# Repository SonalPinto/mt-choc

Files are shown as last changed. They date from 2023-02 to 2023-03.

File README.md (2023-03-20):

# Mt. Choc
<p align="center" width="100%">
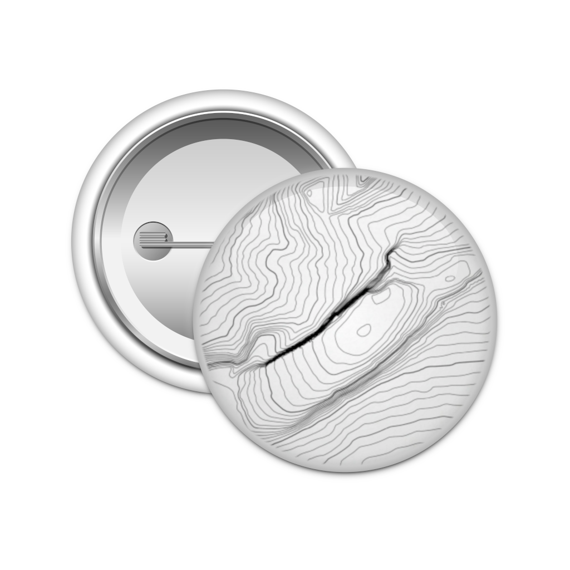
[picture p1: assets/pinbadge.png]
    
</p>

Mt. Choc is a low-profile 65% ~dark chocolate~ keyboard with a digital pin badge.







## News
- [Mt. Choc on KBD.news](https://kbd.news/Mt.-Choc-1938.html) 🎉

<p align="center" width="100%">
    <a href="http://www.youtube.com/watch?feature=player_embedded&v=3p3KzxKYGxo" target="_blank">
     Mt. Choc Glitch Effect
    </a>
</p>

## Gallery
<p align="center" width="100%">
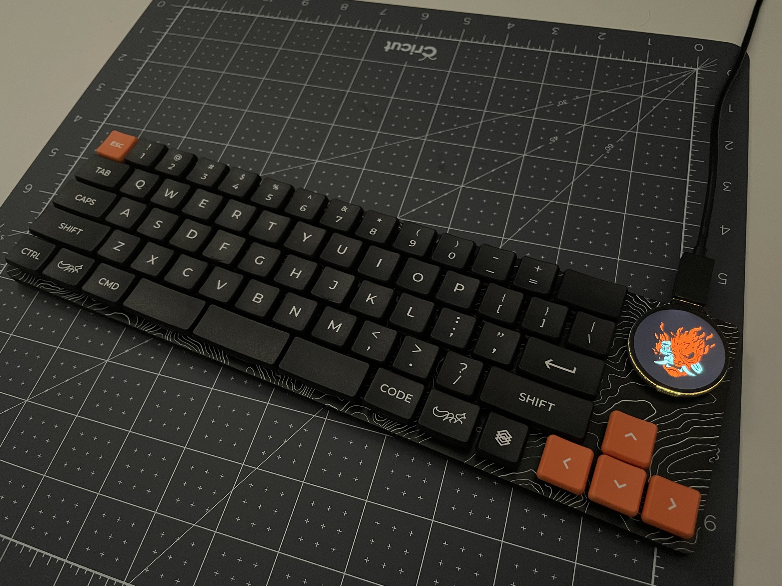
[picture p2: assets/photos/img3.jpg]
    
</p>
<p align="center" width="100%">
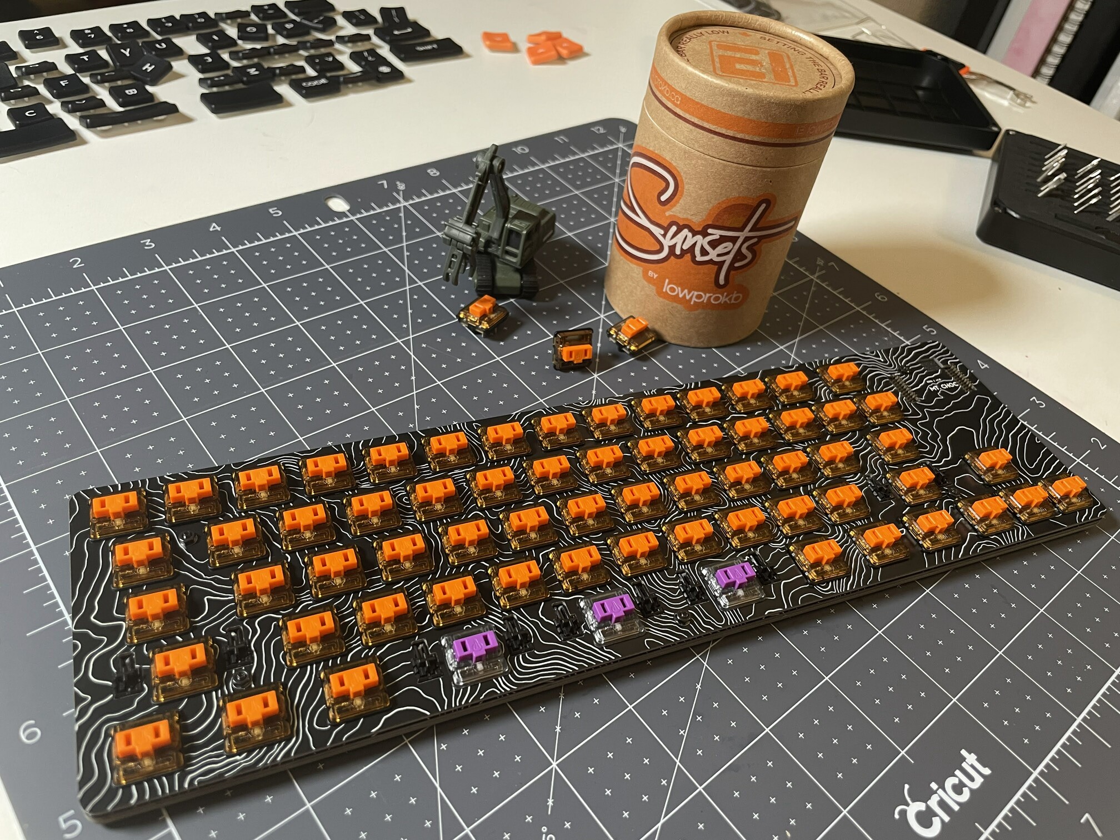
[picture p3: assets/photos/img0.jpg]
    
</p>
<p align="center" width="100%">
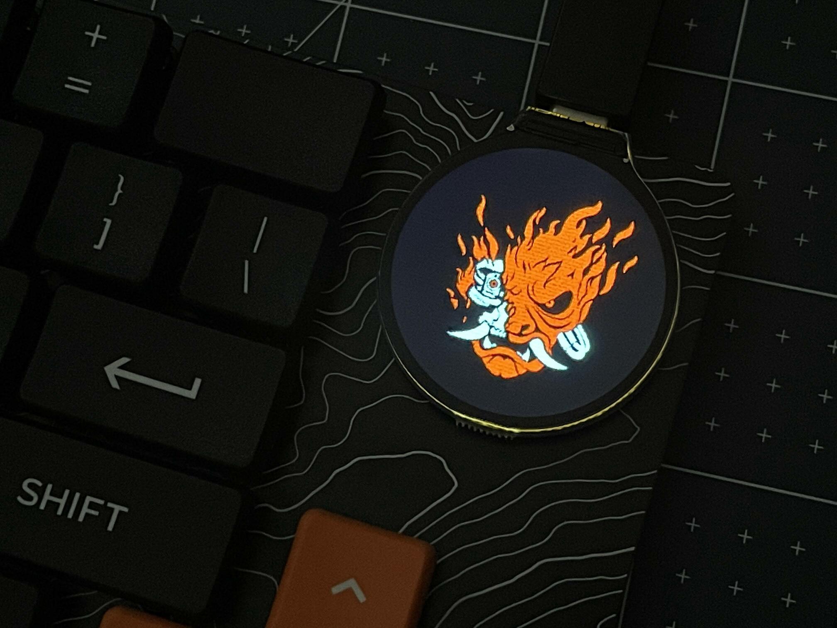
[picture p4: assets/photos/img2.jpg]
    
</p>
<p align="center" width="100%">
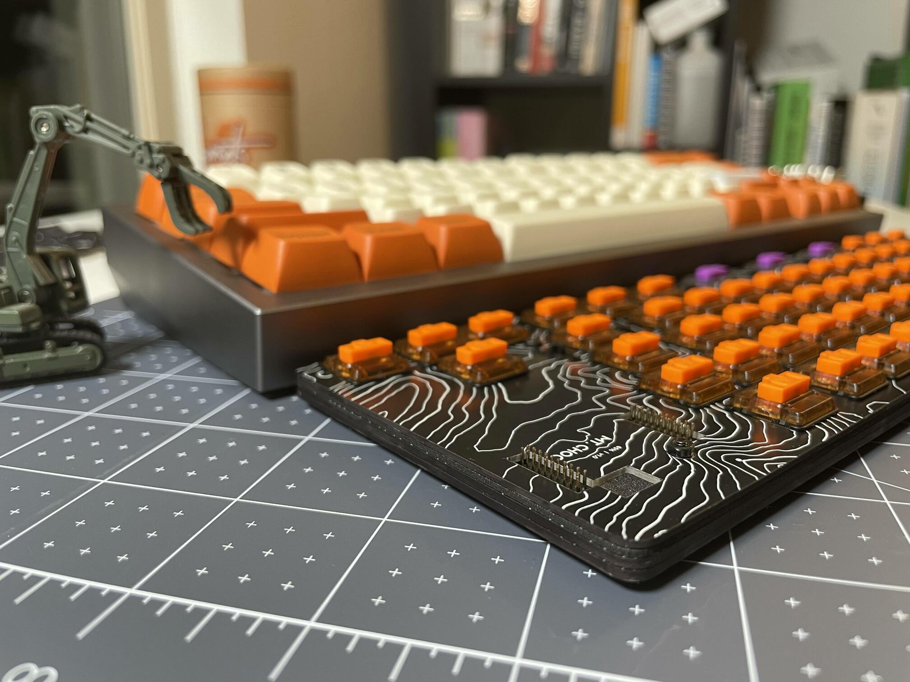
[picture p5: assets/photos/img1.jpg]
    
</p>

## Layout
A while back I had bought a box of [Sunset tactiles](https://lowprokb.ca/collections/keyboards/products/sunset-tactile-choc-switches) on a whim. I didn't really have a board in mind back then, but I knew I wanted to design a low profile board and have some kinda display on it. I had some idea brewing around since reading this ["Cyberpunk OLED glitch"](https://kbd.news/Cyberpunk-OLED-glitch-1098.html) article on KBD.news. A few weeks later, I stumbled upon [Simon's interview](https://kbd.news/Keycaps-design-and-free-kittens-1801.html) on KBD.news and saw the interest check for [MBK Legend‡ Extended](https://fkcaps.com/keycaps/mbk/legend-extended)). Everything just clicked together, and I started drafting a board.

Mt. Choc's 65% layout is designed around Kailh Choc V1 (PG1350) switches and choc-spaced keycaps (18mm wide x 17mm tall, like MBK Legend‡ Extended). The rows have the standard stagger and 6.25U spacebar. The right column is a tad narrower than usual with the intention of reducing the number of stabilizers needed. Hence, the backspace is 1.5U, the forward slash is 1U, enter is 1.75U and the right shift is 2.25U (symmetric with the left shift). The arrow cluster is offset 0.25U to right-align with the microcontroller and display. The layout does look simillar to 68-key boards like  the [Ikki68 Aurora](https://shop.wuquestudio.com/pages/ikki68-aurora) or [Varmillo Miya or VA68](https://en.varmilo.com/keyboardproscenium/product_indexsubject?layout=65&model=Theme%20keyboard), with the 2x2 keys in the top-right swapped for the display. The design is very human.

<p align="center" width="100%">
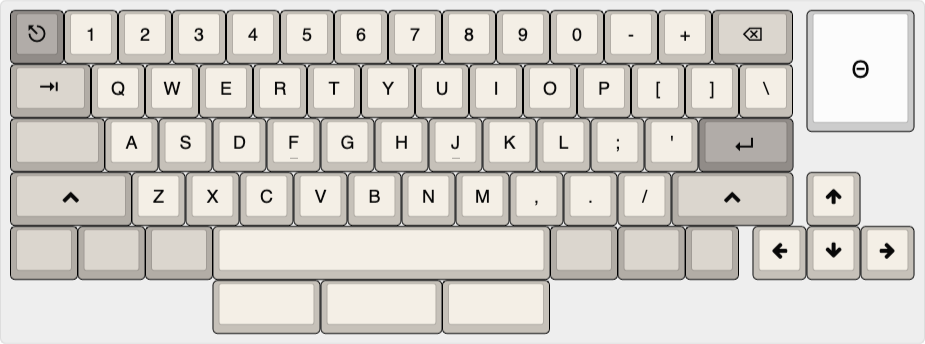
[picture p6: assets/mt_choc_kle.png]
    
</p>

The 2.25U shift on the left and right will need choc 2U stabilizers (standard 24mm wire). The 6.25U MBK spacebar uses a stabilizer that is 100mm apart (MBK spec). Opportunistically, the layout also offers an alternate spacebar layout with a split (2U-2.25U-2U) that reuses the stabilizer footprint cutouts of the 6.25U (read more in the [hardware doc](docs/hardware.md)).

With the split spacebar layout, you are left with 2U and 2.25U that use stabilizers. You could brave a build without stabilizers for these, and see where that takes you. The MX-spaced [wrk keycaps](https://worklouder.cc/keycaps/) do not appear to be using stabilizers for their 2U. I've tried this, and I wasn't a fan. So, I recommend using stabilizers for anything over 2U.

Lastly, the [round display](https://www.waveshare.com/wiki/RP2040-LCD-1.28) is like a digital pin badge for your keyboard. Give it a personal flair!

<p align="center" width="100%">
    
</p>

## Hardware
[⌨️ DOC ⌨️](docs/hardware.md)

## Build
[⌨️ DOC ⌨️](docs/build.md)

## Firmware
[⌨️ DOC ⌨️](docs/firmware.md)

## Misc
- Keyboard Layout Editor - [link](http://www.keyboard-layout-editor.com/#/gists/bee63da1aabd22d248c2b8acba987245)
- KLE raw txt - [link](docs/mt-choc-kle.txt)
- Kailh choc stabilizer spec - [link1](https://github.com/keebio/keebio-references/tree/master/Kailh%20Choc%20Stabs), [link2](assets/choc-stab-spec.jpg), [3D model](https://grabcad.com/library/kailh-choc-v1-pg1350-stabilizer-1)
- Kailh choc PG1350 spec - [link](https://cdn-shop.adafruit.com/product-files/5113/CHOC+keyswitch_Kailh-CPG135001D01_C400229.pdf)
- Kailh choc hotswap socket - [link](https://cdn-shop.adafruit.com/product-files/5118/5118-Choc-Socket.pdf)

### Compatible Keycaps
Keycaps designed for 18mm wide 1U. This is not an exhaustive list.
- [MBK Legend‡ Extended](https://fkcaps.com/keycaps/mbk/legend-extended)
- [MBK Convex POM](https://www.moergo.com/collections/mbk-convex-keycaps/products/mbk-pom-pk2?variant=44253211722001). The 2U and 2.25U would be well suited for the split spacebar. Note, this is not the same as FK Caps MBK.
- [MCC keycaps](https://splitkb.com/products/moergo-mcc-profile-1u-keycap)
- [ChosFox CFX](https://chosfox.com/products/chocfox-legends-keycap-set?variant=42753190461634). Ok, technically, I am not sure if CFX was designed for 18mm wide spacing. My measurements say that they may have been designed for 19mm (or 19.05mm) spacing. However, when placed on the 18mm wide spaced board, I couldn't tell if anything was off (at least the left/right mod columns appear ok~ish).

## Credits
- Simon ([FK Caps](https://fkcaps.com/)) and folks on FK Caps [Discord](https://discord.gg/b5C9H99RYZ)
- skarrman's [Horizon keyboard](https://github.com/skarrmann/horizon/)
- FK Caps [mbk-footprints](https://github.com/FKcaps/mbk-footprints)
  - Based off of nicoles' [mbk-footprints](https://github.com/nicoles/mbk_footprints)
- Wife for photography and coming up with the name

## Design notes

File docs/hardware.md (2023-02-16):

# Hardware

The **minimalist** build for Mt. Choc is inspired by the "PCB-Enclosed" design of the [Horizon Keyboard](https://github.com/skarrmann/horizon/), where the main PCB is enclosed by a another PCB with cutouts for the components. This builds for an excitingly low height stack!

<p align="center" width="100%">
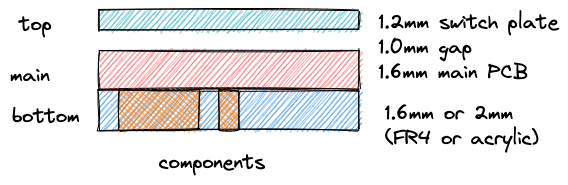
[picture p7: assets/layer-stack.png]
    
</p>

## Microcontroller
The board is powered by a [Waveshare RP2040 microcontroller](https://www.waveshare.com/rp2040-lcd-1.28.htm) with integrated 1.28" display (GC9A01A, 240x240px). The board has two 2x10 headers (1.27mm pitch) with a decent number of GPIO brought out. I picked this one because the display seemed fun, and the overall profile is pretty neat, and for the RP2040.

Since I couldn't find a footprint for this board, I had to draw one. The footprint base for the uC was extracted from the model linked in its [waveshare docs](https://www.waveshare.com/wiki/RP2040-LCD-1.28). Then, project the model onto an offset plane and export the sketch as DXF. This can be imported in KiCad Footprint Editor as a graphic for further cleanup.

<p align="center" width="100%">
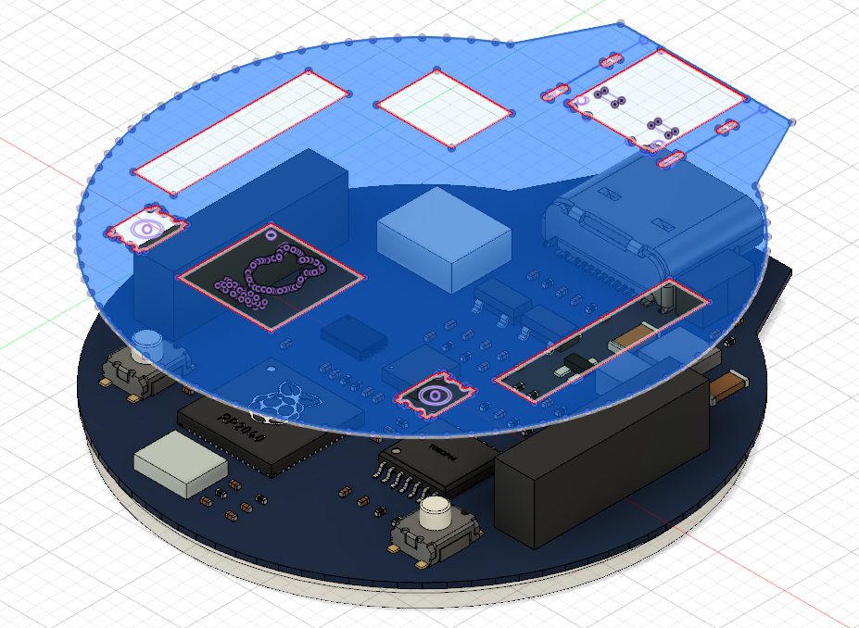
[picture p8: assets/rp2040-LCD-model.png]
    
</p>

The uC has footprints for all the three layers. The main PCB is the one with the soldered through-hole male headers (two 2x10 1.27mm pitch). So, the bottom will need some cutout for the pins and pads. The switch plate cutouts has clearances for the female headers on the uC and the MX1.25 battery header. The buttons and the USBC header have enough clearance above the switch plate to not require cutouts. However, I've also added a footprint for a larger cutout following the outer profile in the [library](../pcb/footprints/mt-choc-footprints.pretty), though I haven't used it in this design. The edge.cuts are in orange, below.

<p align="center" width="100%">
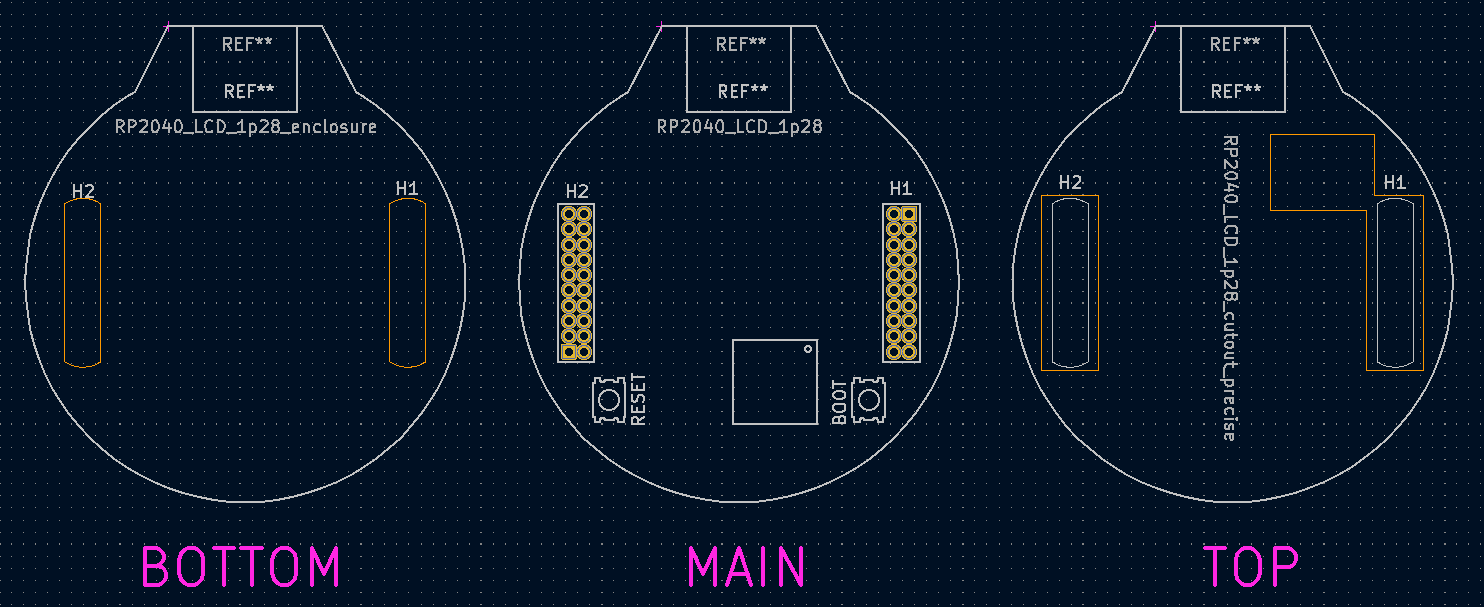
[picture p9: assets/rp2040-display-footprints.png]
    
</p>

## Stabilizers
The choc keycaps that need stabilizers (and wish to use Kailh Choc Stabilizers) apparently have an orientation, because the stabilizer stems ("+") and the switch do not sit in a straight line (Fig. 1). The footprint confirms this as well (Fig. 2). Moreover, the stabilizer itself cannot be moved to be collinear with the switch because there is not enough room to move the stabilizer wire down (Fig. 3).

<p align="center" width="100%">
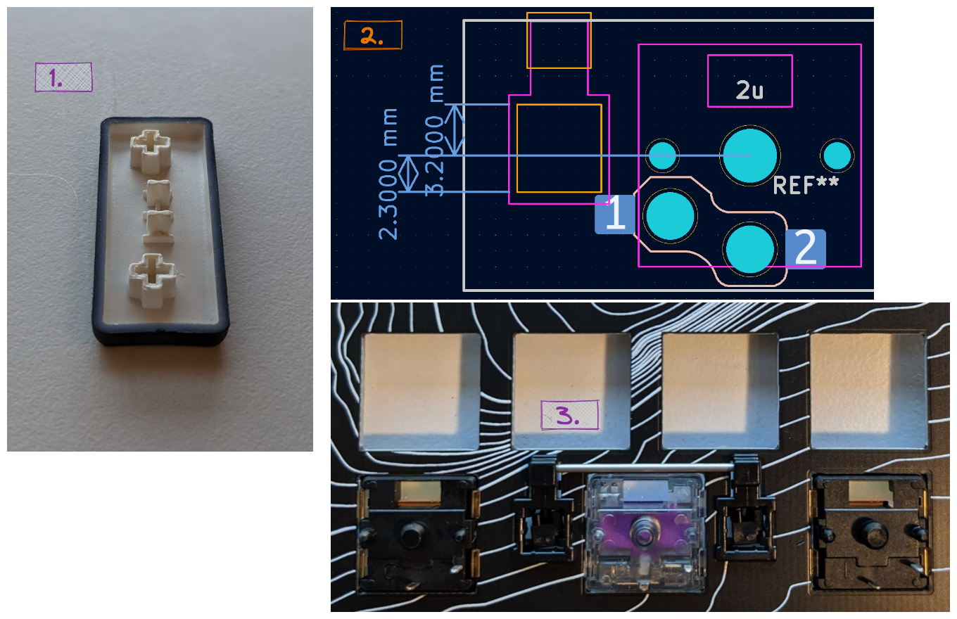
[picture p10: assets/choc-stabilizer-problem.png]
    
</p>

Now, usually for blanks this wouldn't be a problem. However, with legends, the keycaps need to sit in a right way. For MBK, we need **north-facing** stabilizers.

<p align="center" width="100%">
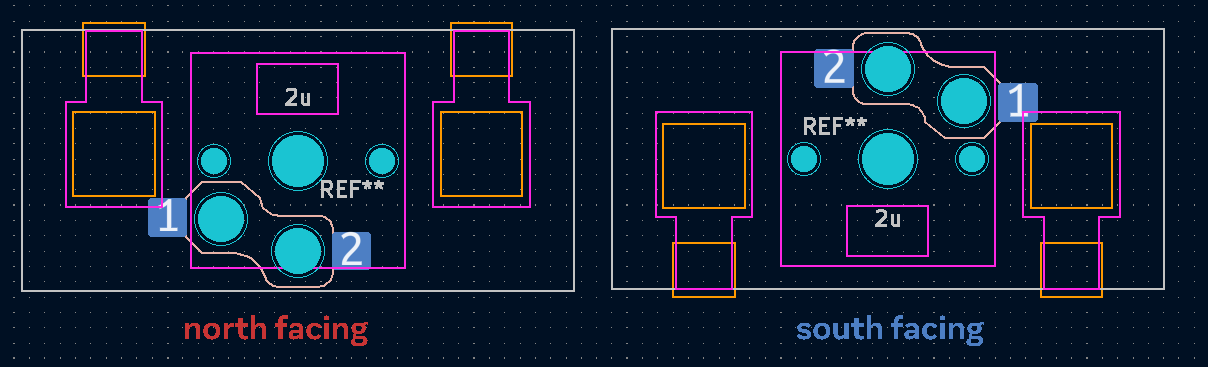
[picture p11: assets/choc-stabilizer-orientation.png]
    
</p>

## Spacebar

The 6.25U spacebar is great. But, there is clearly an opportunity to squeeze a split spacebar in there. Two 2U align with the outermost stabilizer cutouts, and a 2.25U in the center aligns with switch footprint for the 6.25U. Now, since the the 2U is aligned to the stabilizer cutout of the 6.25U, the 2U is shifted in by 0.25mm (shown by the third row below). So the gaps between the 2U and 2.25 will be smaller than usual (by 0.25mm each), and the gap between the 2U and the outer 1.25U will be wider than usual (by 0.25mm).

<p align="center" width="100%">
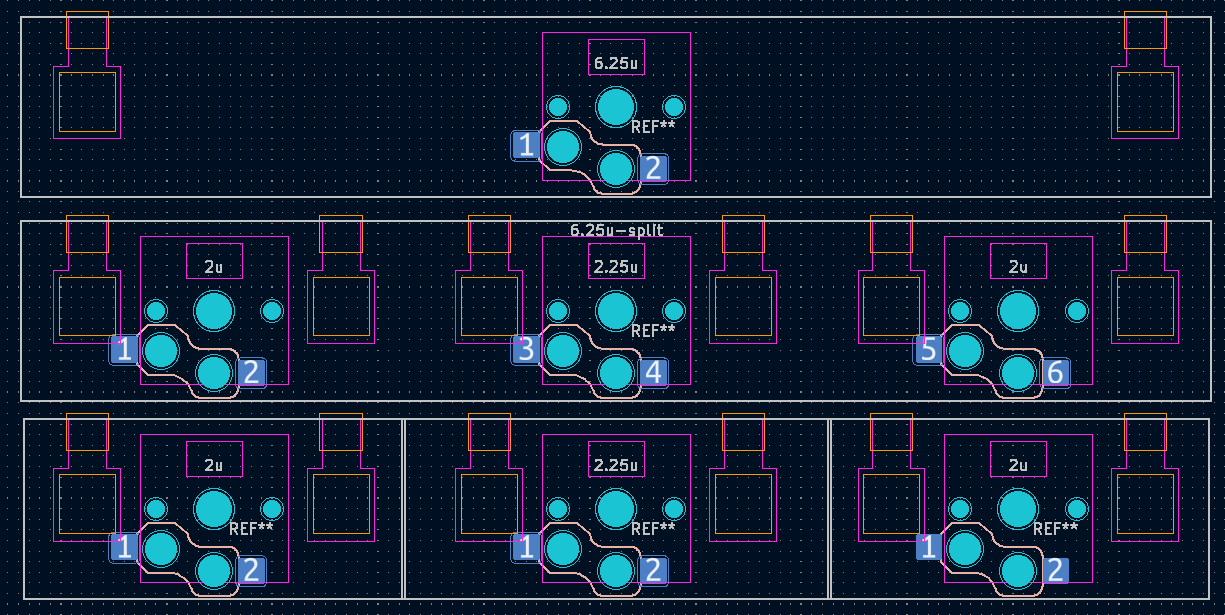
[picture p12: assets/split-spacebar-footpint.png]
    
</p>

The 6.25U MBK spacebar needs a 100mm wire, which is the same width as an MX wire. However, the default long wire that comes along with a Kailh Choc stabilizer kit is 76mm long. Moreover, the MX 100mm wire probably cannot be used with the choc stabilizers because they are usually taller (12.5mm), whereas the Kailh stabilizers are 10mm tall. Moreover, they are also thicker and don't seem to fit into the Kailh choc stabilizer stems (at least the ones I have tried).

The split spacebar requires three 2U choc stabilizers, instead.

## Bottom Plate

Optimistically, every switch takes the [choc-1U-enclosure](../pcb/footprints/Choc-1u-enclosure.kicad_mod) footprint. Cutouts for the stabilizer do not appear to be necessary, since the stem does not appear to pass through the 1.6mm main PCB (though it does pass into it). At least not in the prototypes I tested. However there are some pessimistic bottom plate cutout footprints in the [library](../pcb/footprints/mt-choc-footprints.pretty) as well for 2U and 6.25U.

<p align="center" width="100%">
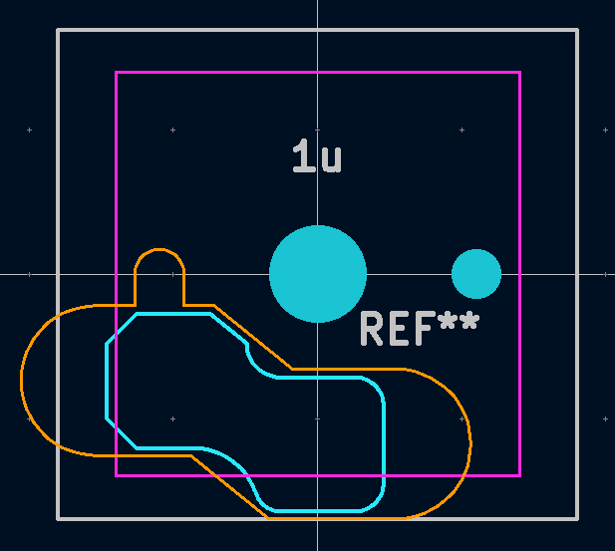
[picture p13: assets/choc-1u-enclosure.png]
    
</p>

## Soldering

- Get a Pinecil, and invest in some good solder (Kester 0.02" 63/37) and wick (Chemtronics or MG Chemicals). Get some tip tinner (Thermaltronics), and flux (ChipQuik) too.
- Be careful with diode orientation. There is a silkscreen marker to indicate placement.
- Same goes for the hotswap sockets. Now, usually this isn't a problem on regular builds, which don't use a bottom plate to **enclose** the main PCB. Because, the Kailh hotswap sockets are mechanically and electrically symmetric. However, if the build uses the bottom plate to enclose the components, then the hotswap sockets must be soldered along the indicated silkscreen silhouette.
- Soldering the 1.27mm pitch headers can be tricky. Might be the trickiest part of the job, and might be worth starting the build with this step.
  - Stick the male headers into the microcontroller first, and then set it onto the PCB. Use some painter's tape (or kapton) to hold it in place.
  - Solder **one** corner pin. Confirm everything is good on the other side, and only then proceed to solder another corner pin on the other header. If the setting is off, then reheat that pin while pressing down on the uC from the other side.
  - Iteratively solder the other corners.
  - With great patience, solder the rest the of the pins. If it bridges, then some combo of more solder, flux and wick will fix it.

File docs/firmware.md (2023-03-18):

# Firmware

The [Waveshare-RP2040-LCD-1.28](https://circuitpython.org/board/waveshare_rp2040_lcd_1_28/) is now supported by CircuitPython, as of the 8.0.0 release. Mt. Choc uses [KMK](http://kmkfw.io/) for firmware, same as [Purple Owl](https://github.com/SonalPinto/purple-owl).

## Instructions
- Get CircuitPython installed on the RP2040-LCD board.
- Unzip lib to extract the dependancy modules and copy them over to the CircuitPython/lib directory. This includes KMK.
- Copy `code.py`, `boot.py` and `display.py` into the CircuitPython drive.
- ???
- Profit 💸

## Dependancies
These modules are required aside from the native CircuitPython modules. A bundle with these modules precompiled is available in the as [lib.zip](../firmware/lib.zip) in the firmware directory. These modules need to placed within the `lib` directory of the CircuitPython drive.
- [KMK](http://kmkfw.io/)
- [adafruit_imageload](https://github.com/adafruit/Adafruit_CircuitPython_ImageLoad)

## Boot
The [`boot.py`](../firmware/boot.py) by default will only enumerate the USB HID device. To enter into CircuitPython dev mode with various USB enumerations and access to the RP2040 storage, press ESC as the keyboard is powered on.

## Keyboard
Mt Choc runs on KMK. It is astoundingly simple to use and configuring even the wildest keyboards. The layout mapping for the diode matrix is defined in the [`code.py`](../firmware/code.py) which also enumerates the [`Display`](../firmware/display.py) for the pin badge.

## Pin Badge

The diplay glitch animation is a nifty trick played with CircuitPython displayio.TileGrid. The a reel of frames is loaded in as a bitmap, where each frame is 160x180ps. The below reel has 4 frames collated into a bitmap of 640x180.

<p align="center" width="100%">
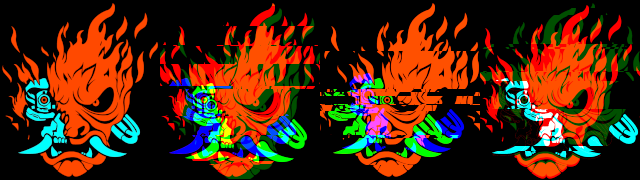
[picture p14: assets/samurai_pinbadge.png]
    
</p>

A TileGrid is setup across a space of 160x180px with say, 1 column and 10 rows, and the larger bitmap is bound to it. Therefore, across the entire bitmap, there are (1 * 4) * 10 = 40 tiles! Though only 10 of these are in the "visible" at any point of time. The animation effect randomly swaps out the tiles across the frames, every cycle.

The `Display` module is not entirely generic, but it isn't too specific either. So it is possible to load a bitmap reel with more frames (as long as it can be loaded into memory) or go wild with the glitch effect configuration. Do ensure that the bitmap is paletted and using few colors (<=16).

https://user-images.githubusercontent.com/8972905/226076137-39ad3e6d-f04e-4504-a3f6-302d70fa951c.mp4

<br></br>
Initially, I had wanted to entirely procedurally generate the glitch effect on the fly by sampling some coherent noise and using displacement maps across the channels. However, after playing with CircuitPython and the display, I ran in to the hard wall of what was realistically computable on a RP2040 running CircuitPython. As of right now, CircuitPython uses only one core of the RP2040. It would have been nice to have KMK on one core and the display animation and management on another core. Fancier things are clearly possible on the RP2040, no doubt - as evidenced by the [PicoSystem](https://shop.pimoroni.com/en-us/products/picosystem) . But that trades off the utter convinience of KMK and CircuitPython, which I am not willing to let go of yet.

## QMK
You could possibly run QMK on this. Afterall, it's just an RP2040. Not too sure about the display though, since I haven't dabbled with QMK.

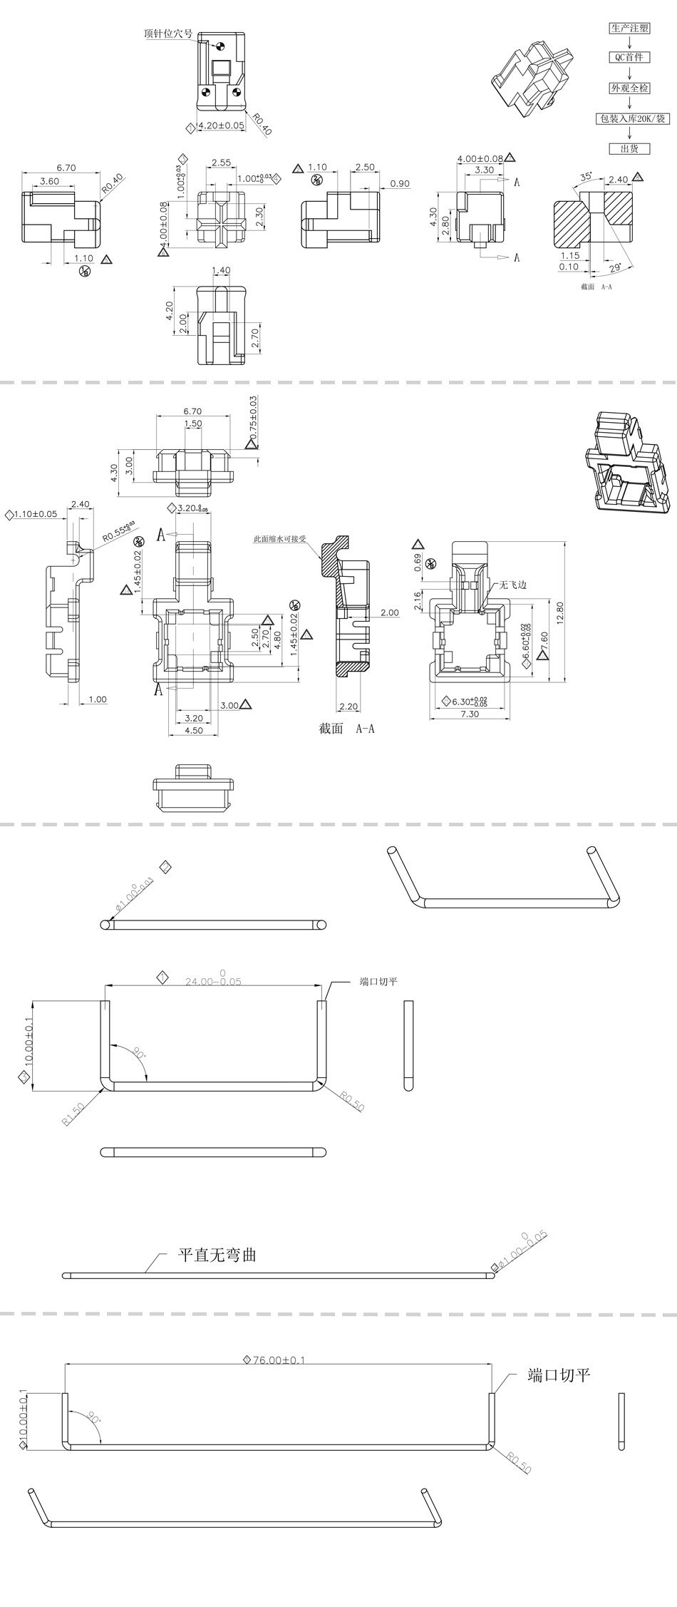
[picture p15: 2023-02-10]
assets/choc-stab-spec.jpg

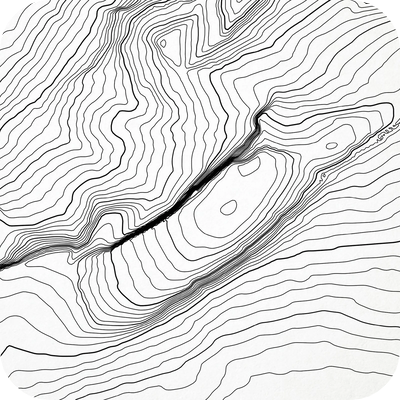
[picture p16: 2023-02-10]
assets/Half-Dome-Topo.png

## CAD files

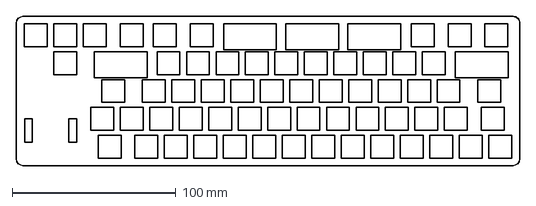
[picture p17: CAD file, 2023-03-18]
case/minimalist/mid-plate.dxf
307.5 x 91.0 mm

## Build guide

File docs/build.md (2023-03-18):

# Build

At the least the build requires the main pcb and the switch plate. This can either be housed naked in the minimalist stack with a component enclosing bottom plate or a 3D printed case for a more enclosed look.

> Note: Vendors are only examples or recommendations. Not endorsing them one way or the other. No affiliations with them.

| Part | Quantity | Description |
| ---| --- | --- |
| Main PCB  | 1 | [gerbers](https://github.com/SonalPinto/mt-choc/tree/main/pcb/v1.0/fab/main), 1.6mm PCB  |
| Switch Plate  | 1 | [gerbers](https://github.com/SonalPinto/mt-choc/tree/main/pcb/v1.0/fab/top), 1.2mm PCB  |
| RP2040-LCD-1.28 | 1 | [waveshare](https://www.waveshare.com/rp2040-lcd-1.28.htm) |
| Male Headers | 2 | [amazon](https://www.amazon.com/dp/B07WHZ2XKK?psc=1&ref=ppx_yo2ov_dt_b_product_details), 2x10 1.27mm pitch |
| Diodes | 66 | [adafruit](https://www.adafruit.com/product/5099), 1N4148 SOD-123 package |
| Kailh Choc hotswap sockets | 66 | [adafruit](https://www.adafruit.com/product/5118) |

#### Notes
- The switch plate should be a 1.2mm PCB order so that the choc switches and stabs slot in correctly.
- PCB can be ordered from fabs like [JLCPCB](https://jlcpcb.com/).
  - You may be charged a little extra ($7.5) for the switch plate for "having too many cutouts", i.e. a [routing fee](https://support.jlcpcb.com/article/62-what-cases-will-be-charged-of-extra-cost).

### Minimalist Stack
For a minimalist look, throw in the bottom plate and foam mid-layer. The bottom plate will enclose the components of the main PCB and the foam layer will fill in the 1mm gap between the switch plate and the main PCB. The bottom plate needn't be a PCB, and can be laser cut with 2mm acrylic as well, same as the foam.

<p align="center" width="100%">
    
</p>

| Part | Quantity | Description |
| ---| --- | --- |
| Bottom Plate  | 1 | [gerbers](https://github.com/SonalPinto/mt-choc/tree/main/pcb/v1.0/fab/bottom), 1.6mm PCB  |
| Mid Plate  | 1 | [DXF](https://github.com/SonalPinto/mt-choc/tree/main/case/minimalist/mid-plate.dxf), [amazon](https://www.amazon.com/dp/B09NB56KPH?psc=1&ref=ppx_yo2ov_dt_b_product_details), 1mm EVA foam, laser cut  |
| M2 Screws | 5 | 8mm, preferably flat head, [amazon](https://www.amazon.com/gp/product/B07TDHZJLL/ref=ppx_yo_dt_b_asin_title_o03_s01?ie=UTF8&psc=1) |
| M2 Nuts | 5 | [amazon](https://www.amazon.com/gp/product/B09ZHHSY92/ref=ppx_yo_dt_b_asin_title_o03_s01?ie=UTF8&psc=1) |

#### Notes
- The mid-plate DXF is exact, i.e. dimensions match the main PCB and switch plate. However, the kerf of the laser can cut way more material (like maybe 1mm) with soft foam like EVA. So, if using foam for the mid-plate, then account for that and use a lower power run. As well, grow the outer shape, and then once assembled cut the excess with an xacto knife.
- There are no holes for the screws in the mid-plate. With foam, you can just poke through it with a pin, and then set the screw.

<p align="center" width="100%">
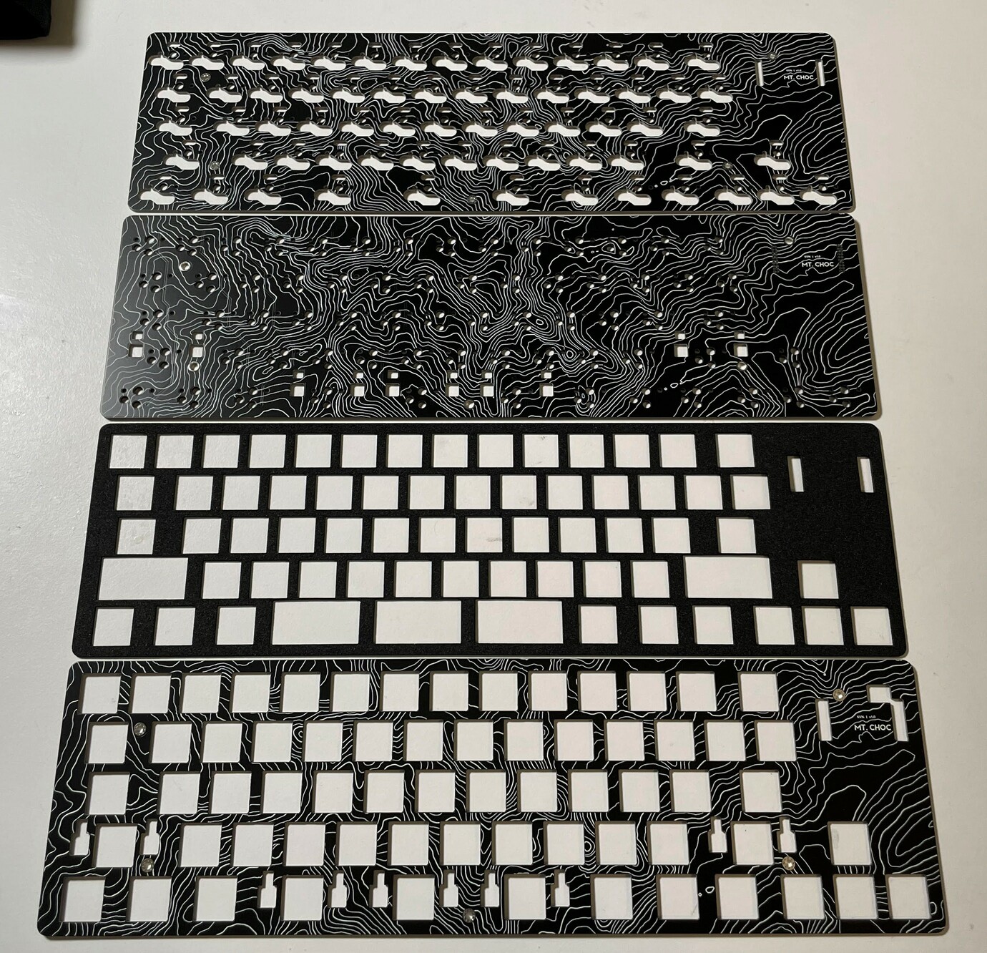
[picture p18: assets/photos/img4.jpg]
    
</p>

#### Assembly
- Solder up the main PCB, and confirm everything works as you go along. [Do read this](https://github.com/SonalPinto/mt-choc/blob/main/docs/hardware.md#soldering).
- Lube the choc stabs and set them into the switch plate - [instructions](https://docs.keeb.io/choc-stabs).
- Setup the 4 layers, and fix them with the screws/nuts.
- Screws are driven in from the bottom. The nuts will be more or less hidden under the keycaps.
- Mount the switches while supporting the sockets from the back, to make sure they don't get ripped off the pads while pushing the socket in.
- Use a sharpie to darken the sides of the PCB.

### 3D Printed Case
- TODO

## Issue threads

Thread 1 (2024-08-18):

Compatibility with Circuit Python 9.1.1

Neosky123, 2024-08-18:
When I install Circuit Python 9.1.1, I get an error about incompatible KMK firmware.
The KMK firmware must be cross-compiled again to match the Circuit Python 9.1.1 version.

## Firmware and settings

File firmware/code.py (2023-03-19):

"""
Mt Choc v1.0 KMK Build
"""

import board
import busio
import displayio
import adafruit_imageload

from kmk.kmk_keyboard import KMKKeyboard
from kmk.keys import KC
from kmk.scanners import DiodeOrientation
from kmk.modules.layers import Layers
from display import Display

class MtChoc(KMKKeyboard):
    def __init__(self):
        # =============================================================
        # Scanner
        self.diode_orientation = DiodeOrientation.COL2ROW

        self.col_pins = (
            board.GP28,     # col-1 (left)
            board.GP27,
            board.GP26,
            board.GP16,
            board.GP17,
            board.GP18,
            board.GP19,
            board.GP20,
            board.GP21,
            board.GP22,
            board.GP2,
            board.GP3,
            board.GP4,
            board.GP5,      # col-14 (right)
        )

        self.row_pins = (
            board.GP0,      # row-1 (top)
            board.GP1,
            board.GP15,
            board.GP14,
            board.GP13,     # row-5 (bottom)
        )

        # =============================================================
        # Physical Layout
        self.coord_mapping = [
            0,  1,  2,  3,  4,  5,  6,  7,  8,  9,  10, 11, 12, 13,
            14, 15, 16, 17, 18, 19, 20, 21, 22, 23, 24, 25, 26, 27,
            28, 29, 30, 31, 32, 33, 34, 35, 36, 37, 38, 39, 40,
            42, 43, 44, 45, 46, 47, 48, 49, 50, 51, 52, 53, 54,
            56, 57, 58,     60, 61, 62,     64, 65, 66, 67, 68, 69
        ]

        # =============================================================
        # Extensions
        layer_ext = Layers()
        display_ext = Display(imgfile="/samurai_pinbadge.bmp", grid_rows=5, grid_columns=4)

        self.modules = [layer_ext, display_ext]

        # =============================================================
        # Keymap
        _______ = KC.TRNS
        XXXXXXX = KC.NO

        # Layers
        LOWER = KC.MO(1)
        RAISE = KC.MO(2)

        self.keymap = [
            [   # Base
                KC.ESC,   KC.N1,    KC.N2,    KC.N3,    KC.N4,    KC.N5,    KC.N6,    KC.N7,    KC.N8,    KC.N9,    KC.N0,    KC.MINUS,  KC.EQUAL,  KC.BSPC,
                KC.TAB,   KC.Q,     KC.W,     KC.E,     KC.R,     KC.T,     KC.Y,     KC.U,     KC.I,     KC.O,     KC.P,     KC.LBRC,   KC.RBRC,   KC.BSLS,
                KC.CAPS,  KC.A,     KC.S,     KC.D,     KC.F,     KC.G,     KC.H,     KC.J,     KC.K,     KC.L,     KC.SCLN,  KC.QUOT,   KC.ENT,
                KC.LSFT,  KC.Z,     KC.X,     KC.C,     KC.V,     KC.B,     KC.N,     KC.M,     KC.COMM,  KC.DOT,   KC.SLSH,  KC.RSFT,   KC.UP,
                KC.LCTRL, KC.LALT,  KC.LGUI,            KC.SPC,   KC.SPC,   KC.SPC,             LOWER,    RAISE,    KC.DEL,   KC.LEFT,   KC.DOWN, KC.RGHT,
            ],
            [   # Lower
                KC.GRV,   _______, _______,   _______,  _______,  _______,  _______,  _______,  _______,  _______,  _______,  _______,   _______,   _______,
                _______,  _______, _______,   _______,  _______,  _______,  _______,  _______,  _______,  _______,  _______,  _______,   _______,   _______,
                _______,  _______, _______,   _______,  _______,  _______,  _______,  _______,  _______,  _______,  _______,  _______,   _______,
                _______,  _______, _______,   _______,  _______,  _______,  _______,  _______,  _______,  _______,  _______,  _______,   _______,
                _______,  _______, _______,             _______,  _______,  _______,            _______,  _______,  _______,  _______,   _______,   _______,
            ],
            [   # Raise
                KC.TILD,  _______, _______,   _______,  _______,  _______,  _______,  _______,  _______,  _______,  _______,  _______,   _______,   _______,
                _______,  _______, _______,   _______,  _______,  _______,  _______,  _______,  _______,  _______,  _______,  _______,   _______,   _______,
                _______,  _______, _______,   _______,  _______,  _______,  _______,  _______,  _______,  _______,  _______,  _______,   _______,
                _______,  _______, _______,   _______,  _______,  _______,  _______,  _______,  _______,  _______,  _______,  _______,   _______,
                _______,  _______, _______,             _______,  _______,  _______,            _______,  _______,  _______,  _______,   _______,   _______,
            ],
        ]


if __name__ == '__main__':
    keyboard = MtChoc()
    keyboard.go()

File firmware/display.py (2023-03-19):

"""
Mt Choc KMK Display Extension

Note: This is a specific module, not a generic one.
"""

import board
import time
import random
import gc
import busio
import displayio
import adafruit_imageload

from kmk.extensions import Extension


class Display(Extension):
    # REF: https://github.com/todbot/CircuitPython_GC9A01_demos
    # REF: https://github.com/KMKfw/kmk_firmware/tree/master/kmk/extensions

    # GC9A01 display initialization sequence
    _INIT_SEQUENCE = bytearray(
        b"\xFE\x00"  # Inter Register Enable1 (FEh)
        b"\xEF\x00"  # Inter Register Enable2 (EFh)
        b"\xB6\x02\x00\x00"  # Display Function Control (B6h) [S1→S360 source, G1→G32 gate]
        b"\x36\x01\x88"  # Memory Access Control(36h) [Invert Row order, BGR color]
        b"\x3a\x01\x05"  # COLMOD: Pixel Format Set (3Ah) [16 bits / pixel]
        b"\xC3\x01\x13"  # Power Control 2 (C3h) [VREG1A = 5.06, VREG1B = 0.68]
        b"\xC4\x01\x13"  # Power Control 3 (C4h) [VREG2A = -3.7, VREG2B = 0.68]
        b"\xC9\x01\x22"  # Power Control 4 (C9h)
        b"\xF0\x06\x45\x09\x08\x08\x26\x2a"  # SET_GAMMA1 (F0h)
        b"\xF1\x06\x43\x70\x72\x36\x37\x6f"  # SET_GAMMA2 (F1h)
        b"\xF2\x06\x45\x09\x08\x08\x26\x2a"  # SET_GAMMA3 (F2h)
        b"\xF3\x06\x43\x70\x72\x36\x37\x6f"  # SET_GAMMA4 (F3h)
        b"\x66\x0a\x3c\x00\xcd\x67\x45\x45\x10\x00\x00\x00"
        b"\x67\x0a\x00\x3c\x00\x00\x00\x01\x54\x10\x32\x98"
        b"\x74\x07\x10\x85\x80\x00\x00\x4e\x00"
        b"\x98\x02\x3e\x07"
        b"\x35\x00"  # Tearing Effect Line ON (35h) [both V-blanking and H-blanking]
        b"\x21\x00"  # Display Inversion ON (21h)
        b"\x11\x80\x78"  # Sleep Out Mode (11h) and delay(120)
        b"\x29\x80\x14"  # Display ON (29h) and delay(20)
        b"\x2a\x04\x00\x00\x00\xef"  # Column Address Set (2Ah) [Start col = 0, end col = 239]
        b"\x2b\x04\x00\x00\x00\xef"  # Row Address Set (2Bh) [Start row = 0, end row = 239]
    )

    def __init__(self, imgfile, grid_rows, grid_columns):
        self.grid_rows = grid_rows
        self.grid_columns = grid_columns
        self.effect_init = True

        # Init display hardware with manual refresh control
        displayio.release_displays()

        self.display_spi = busio.SPI(clock=board.LCD_CLK, MOSI=board.LCD_DIN)
        
        self.display_bus = displayio.FourWire(
            self.display_spi, 
            baudrate=62500000, 
            command=board.LCD_DC, 
            chip_select= board.LCD_CS, 
            reset=board.LCD_RST)
        
        self.display = displayio.Display(
            self.display_bus, 
            Display._INIT_SEQUENCE,
             width=240, height=240, 
             backlight_pin=board.LCD_BL, 
             auto_refresh=False)

        # Load up bitmap and setup tilegrid
        # The bitmap is sliced into a grid described by `grid_rows` and `grid_columns`
        # The displayio.tilegrid covers the first column of the bitmap, and the glitch/animation
        # effect procedurally swaps out the row instances from the other columns.
        # Example:
        #       A reel of 160x180px frames can be collated into a 800x180px bitmap
        #       This can be sliced into a grid of 5 columns (160px each) and 10 rows (18px each)!
        gc.collect()
        self.img, self.palette = adafruit_imageload.load(imgfile,
                                    bitmap=displayio.Bitmap,
                                    palette=displayio.Palette)
        
        # Perhaps, the x/y here should be modified based on the image.
        self.tile_grid = displayio.TileGrid(self.img, pixel_shader=self.palette, x=48, y=31,
                            width=1, height=self.grid_rows,
                            tile_height=180//self.grid_rows, tile_width=160)

        # Init frame
        # The tilegrid is initialized to the first column of the bitmap
        self.group = displayio.Group()
        self.group.append(self.tile_grid)
        self.display.show(self.group)

        for i in range(self.grid_rows):
            self.tile_grid[i] = i * self.grid_columns

        # Manual refresh
        self.display.refresh()
        gc.collect()

    def on_runtime_enable(self, sandbox):
        return

    def on_runtime_disable(self, sandbox):
        return

    def during_bootup(self, sandbox):
        return

    def before_matrix_scan(self, sandbox):
        return

    def after_matrix_scan(self, sandbox):
        return

    def before_hid_send(self, sandbox):
        return

    def after_hid_send(self, sandbox):
        self.animate()

    def on_powersave_enable(self, sandbox):
        return

    def on_powersave_disable(self, sandbox):
       return

    def animate(self):
        if self.effect_init:
            self._init_effect()

        T = time.monotonic()
        if T - self.mFrameTime > self.kFrameTime and T - self.mIdle > self.kAnimationCycle:
            self.mFrameTime = T

            # Swap some tiles in the viewport to tiles from the other columns of the bitmap
            if self.mFrame < self.kMaxFrames - 1:
                for i in range(self.kGlitch):
                    row = random.randint(0, self.grid_rows - 1)
                    col = random.randint(1, self.grid_columns - 1)
                    self.tile_grid[row] = row * self.grid_columns + col
                    self.mReset[i] = row

            # Manual refresh
            self.display.refresh()

            # Revert tilegrid
            if self.mFrame < self.kMaxFrames - 1:
                for row in self.mReset:
                    self.tile_grid[row] = row * self.grid_columns

            self.mFrame += 1
            if self.mFrame == self.kMaxFrames:
                self.mFrame = 0
                self.mIdle = time.monotonic()

    def _init_effect(self):
        #
        # Glitch effect parameters
        #

        # Number of animation frames
        self.kMaxFrames = 4
        
        # Extent of glitching effect, i.e. instances of tiles swapped
        self.kGlitch = 2

        # Animation frame time
        self.kFrameTime = 0.15

        # How often the animation is triggered, in seconds
        self.kAnimationCycle = 3

        # Animation trackers
        self.mIdle = time.monotonic()
        self.mFrame = 0
        self.mReset = [0] * self.kGlitch
        self.mFrameTime = 0

        self.effect_init = False

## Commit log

2023-02-12 Add Footprints
    - Add footprints for RP2040-LCD-1p28
    - Add 3D model for RP2040-LCD-1p28
    - Setup hierarchy across docs
    - Add docs for build describing minimalist stackup
2023-02-14 More footprints
    - Probably all that are required
    - Hotswap footprints ported from mbk-footprints - 1u, 1.25u, 1.5u,
    1.75u, 2u, 2.25u, 2.75u, 6.25u
    - Cutouts for 1u, 2u and 6.25u. Rest just use these.
    - Pessimitic PCB Enclosure for 2u and 6.25u. Optimistically 1u could be
    used everywhere.
2023-02-14 Main PCB schematic
    [mt-choc.kicad_pcb, mt-choc.kicad_sch]
2023-02-14 Add soldering tips
2023-02-14 Update to KiCad 7.0
    [mt-choc.kicad_sch]
2023-02-16 Split spacebar and more docs
    [mt-choc.kicad_pcb, mt-choc.kicad_sch]
2023-02-16 Add notes on bottom plate cutouts
2023-02-18 Iniital layout for main PCB
    - Update properties on footprints
    - Main PCB is _technically_ done
    [mt-choc.kicad_sch]
2023-02-21 Finish v1.0 layout
    - Add gerbers for main, top and bottom PCB
    - Update footprints for 6.25u split, and misc
    [mt-choc-CuBottom.gbr, mt-choc-CuTop.gbr, mt-choc-EdgeCuts.gbr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]
2023-02-21 Update main PCB and gerbers
    [mt-choc-CuBottom.gbr, mt-choc-CuTop.gbr, mt-choc-EdgeCuts.gbr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]
2023-03-05 Update main PCB schematic and layout
    - Rewire COL4 and COL12. Previously connected to GP23 and GP24 which are
    used for INT1 and INT2 of the IMU.
    [mt-choc-CuBottom.gbr, mt-choc-CuTop.gbr, mt-choc-EdgeCuts.gbr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]
2023-03-18 Add media and build guide
    [mid-plate.dxf]
2023-03-19 Tune the glitch config
    [code.py, display.py]
2023-03-19 Swap LGUI and LCTRL in the base keymap
    [code.py]
